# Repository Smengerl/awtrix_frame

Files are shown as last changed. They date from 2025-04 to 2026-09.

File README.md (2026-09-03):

# Ultra-low-cost AWTRIX build




AWTRIX is an amazing and highly flexible visualization companion for smart home applications and more. Originally designed to be flashed onto the Ulanzi Pixel Clock (priced at around $50), it also supports custom builds.

I wanted to create a fully featured custom build with a professional look but at a much lower price point than the original. Since I couldn’t find a comprehensive guide, I decided to create one myself.

Full source code for AWTRIX available here: [AWTRIX repo](https://github.com/Blueforcer/awtrix3) 

Features:
- <B>Affordable</B>: Base build costs under $20, while the full feature set is around $25.
- <B>3D Printer Friendly</B>: Designed to fit most popular 3D printers with a minimum bed size of 175mm.
- <B>High-Quality Display</B>: 32x8 pixel WS2812B LED matrix with a light diffuser for a clean "pixelated" look and a sleek "full black" effect when turned off.
- <B>Customizable Design</B>: Easily interchangeable covers in different colors and textures.
- <B>Flexible Mounting</B>: Can be wall-mounted using nails or screws, or used as a standing or laying device.
- <B>Optional Features</B>:
    - Light sensor for automatic brightness adjustment.
    - DFPlayer Mini for MP3 playback.
    - Buzzer for notifications or alarms.

Notes:
- <B>Battery Support</B>: This build does not include battery support, as the high power demands of the display make it impractical.
- <B>Temperature/Humidity Sensor</B>: A sensor is not included in the housing because the heat generated by the display would affect accuracy. Instead, you can use an external weather station sensor and display its readings on the AWTRIX screen.

Examples:
| Time/date (AWTRIX build in) | Spotify (Custom app) | Customization Example (Different Covers) |
| --- | --- | --- |
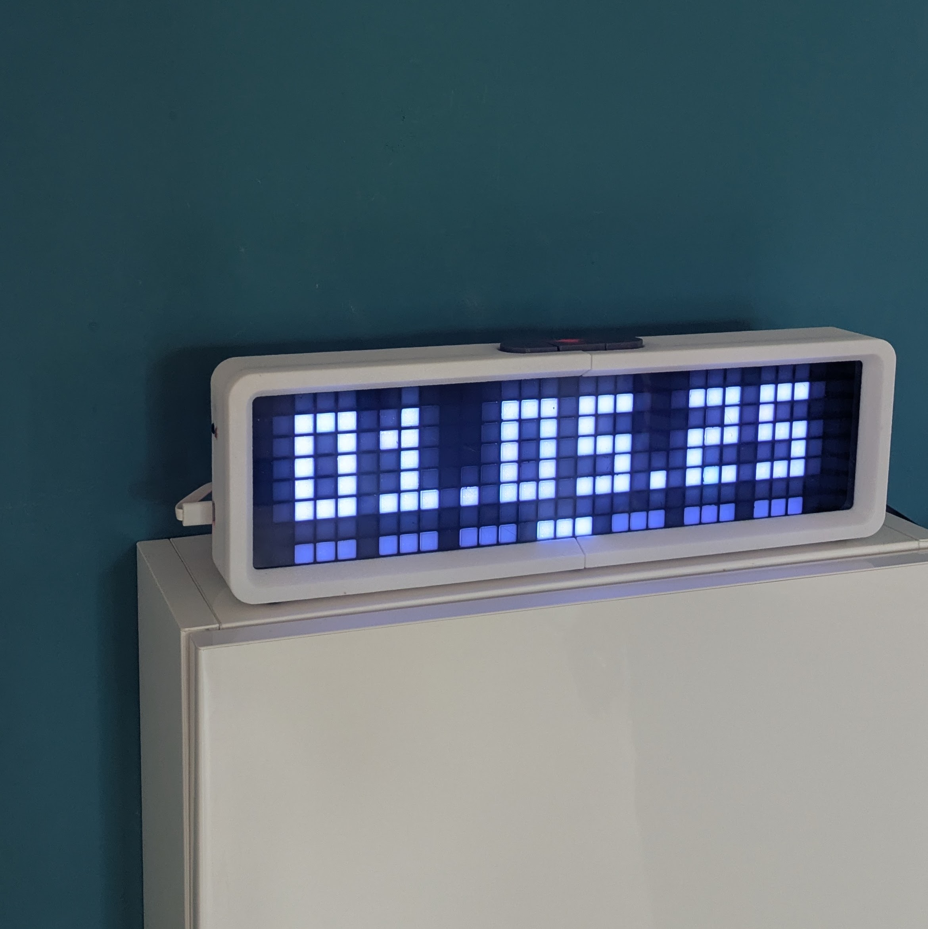
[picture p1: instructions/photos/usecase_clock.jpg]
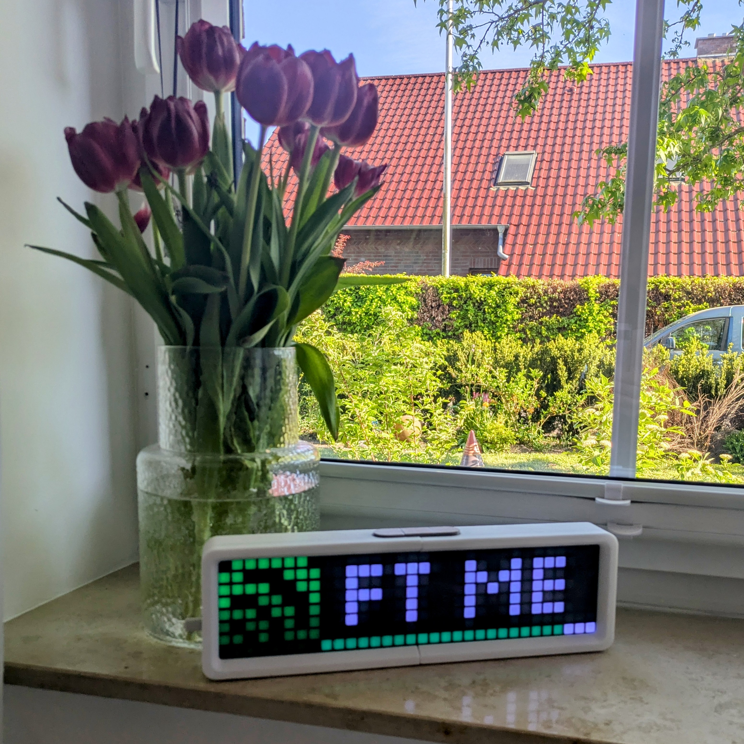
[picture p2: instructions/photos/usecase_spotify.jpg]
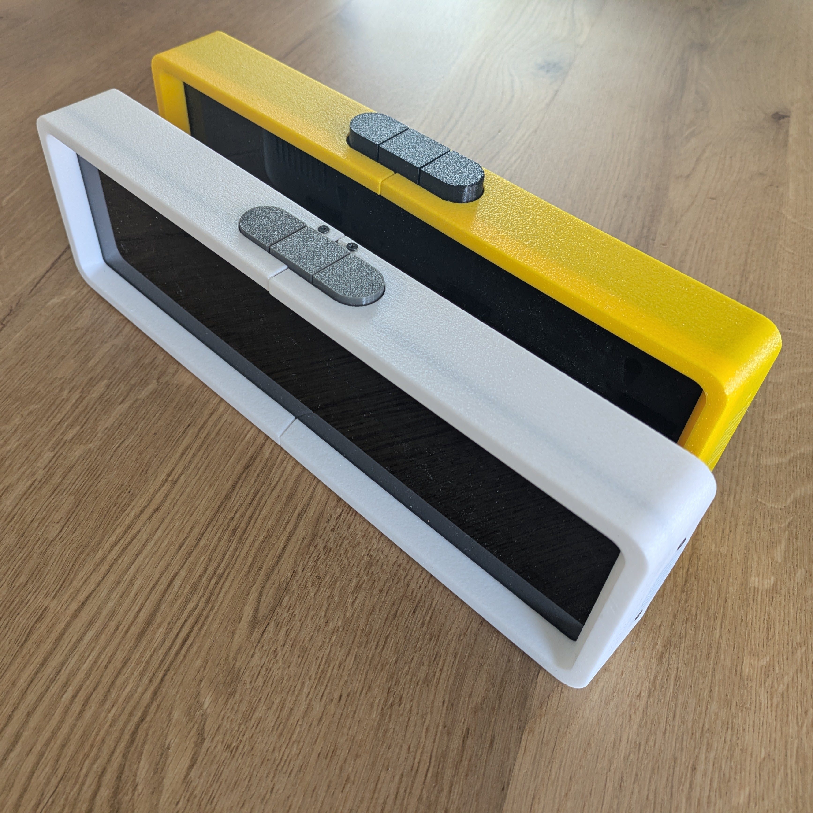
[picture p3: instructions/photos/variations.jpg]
| |  | |

# Index
- [Buy parts](#buy-parts)
- [Printing and assembly](#printing-and-assembly)
- [Customization ideas](#customization-ideas)
- [Acknowledgements](#Acknowledgements)

## Buy parts

Mandatory parts:

| Unit price | Quantity | Partname | Example | Notes |
| --- | --- | --- | --- | ----- |
| 5 USD | 1 | ESP32 Dev Module | <a href="https://de.aliexpress.com/item/1005006124752051.html">AliExpress</a> | Designed for WROVER USB-C type. Other types fit but may require glue |
| 8 USD | 1 | WS2812B matrix 8x32 | <a href="https://de.aliexpress.com/item/4001296811800.html">AliExpress</a> |  |
| 1 USD | 1 | 4 pushbutton element | <a href="https://de.aliexpress.com/item/1005008219549275.html">AliExpress</a> | Connect the outputs of the two middle buttons to "OR" their signal. Unsolder the LED for a cleaner look. |
| 2 USD | 1 | semi-transparent acrylic board | <a href="https://de.aliexpress.com/item/32857098929.html">AliExpress</a> | Optional. Best results with semi-transparent black acrylic (2mm thick). Thinner sheets may need glue. Minimum size: 338x98mm. |
| <1 USD | 25 | Flathead screws M2,5 or M3. 6mm. e.g. DIN 7984 | <a href="https://de.aliexpress.com/item/1005006166060947.html">AliExpress</a> | Use low-head screws (e.g., laptop screws) for a better appearance. |

Optional parts:

| Unit price | Quantity | Partname | Example | Notes |
| --- | --- | --- | --- | ----- |
| 1 USD | 1 | DF Player mini | <a href="https://de.aliexpress.com/item/1005006166800318.html">AliExpress</a> | For MP3 playback |
| 1 USD | 1 | Loudspeaker (8 Ohm) | <a href="https://de.aliexpress.com/item/1005006358049156.html">AliExpress</a> | For MP3 playback. Watch for dimensions |
| <1 USD | 1 | Buzzer | <a href="https://de.aliexpress.com/item/1005004883467830.html">AliExpress</a> | For notifications or alarms. |
| <1 USD | 1 | LDR (GL5516) | <a href="https://de.aliexpress.com/item/1005003021557603.html">AliExpress</a> | For automatic brightness adjustment. |

## Printing and assembly

| 45° | top | -45° | back |
| --- | --- | --- | ---- |
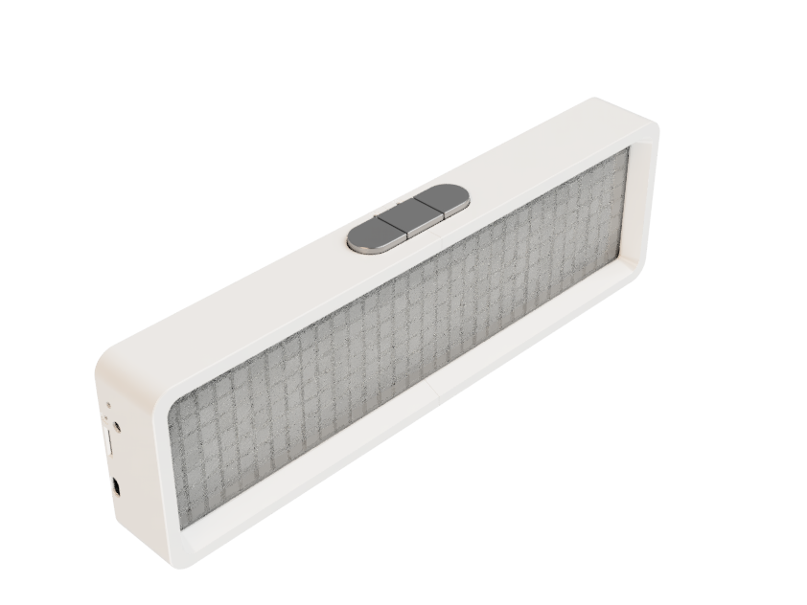
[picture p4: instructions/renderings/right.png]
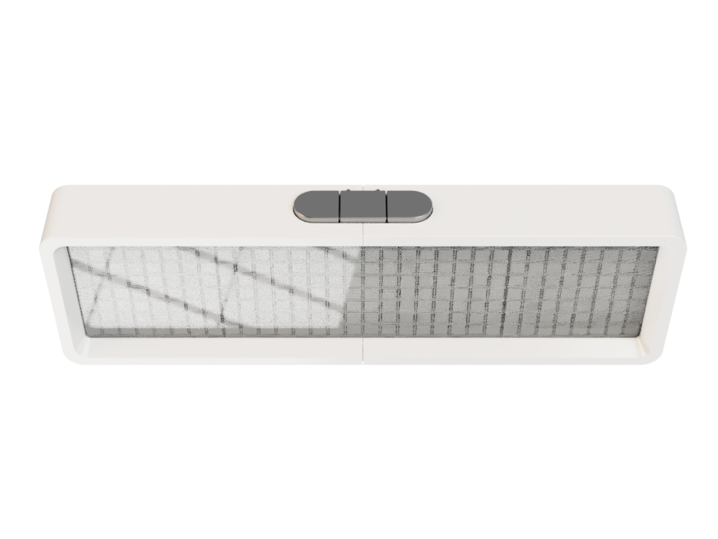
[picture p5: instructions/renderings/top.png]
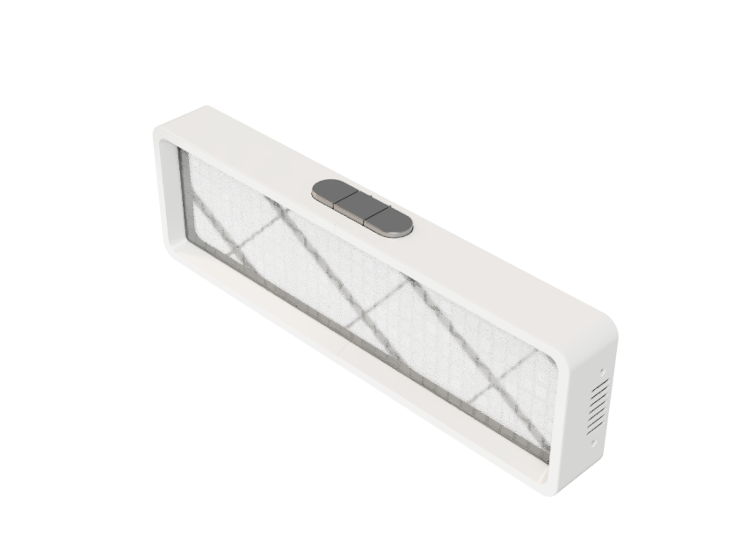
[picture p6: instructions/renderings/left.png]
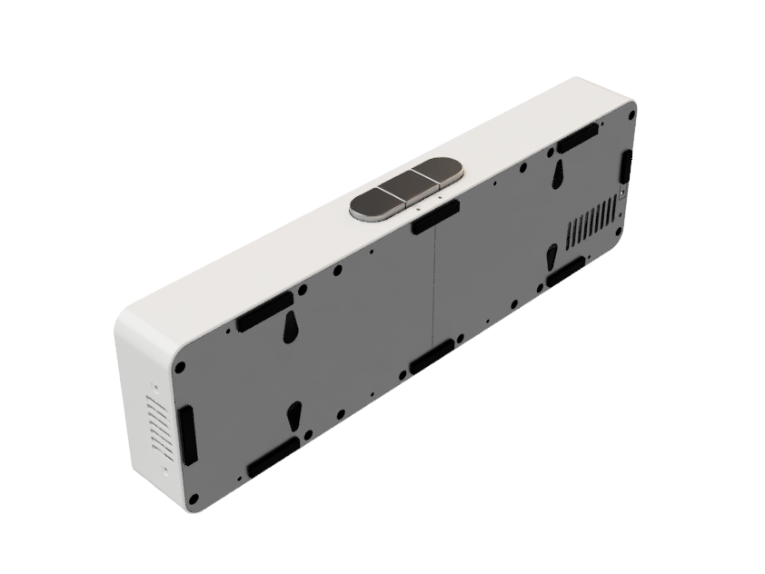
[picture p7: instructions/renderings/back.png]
|  |  |  |  |

The printing and assembly process consist of 5 steps:
- [Step 1: Diffusor](./instructions/step_1.md)
- [Step 2: Base](./instructions/step_2.md)
- [Step 3: Pushbuttons](./instructions/step_3.md)
- [Step 4: Covers](./instructions/step_4.md)
- [Step 5: Anti-slip pads](./instructions/step_5.md)

Printer Settings:
- <B>Material</B>: PETG for most parts, TPU for anti-slip pads, and PLA for the diffuser.
- <B>Orientation</B>: Print parts as shown in the thumbnails for the best results.
- <B>Infill</B>: 20% Gyroid infill with Hilbert curve for first/top layers.
- <B>Supports</B>: Not required unless explicitly mentioned.
- <B>Surface Finish</B>: Use "fuzzy skin" for a textured look on outer walls.
- <B>Rafts/Brims</B>: Not required for any model.

## Customization ideas

The housing offers several customization options:
- Add optional features like the buzzer or light sensor.
- Print covers in different colors or textures.
- Use effects like "fuzzy skin" for a unique appearance.

## Troubleshooting

### External Power

Powering the ESP32 via USB may cause brownouts under LED load. To resolve this, supply regulated 5V directly to the 5V/VIN rail (with a common ground). Use a sufficiently rated 5V supply and thick wiring. Avoid feeding 5V into the USB connector unless using proper power-path/diode.

## Acknowledgements

- Special thanks to Blueforcer for creating the incredible AWTRIX3 project.

## Development

Contributions are welcome.  
See `CONTRIBUTING.md` for details and follow the `CODE_OF_CONDUCT.md` when contributing.

## License

This project is licensed under the Creative Commons Attribution-ShareAlike 4.0 International License (CC BY-SA 4.0) — see `LICENSE.txt` for details or visit http://creativecommons.org/licenses/by-sa/4.0/

## Authors

- Simon Gerlach <https://github.com/Smenger>

---

If something in this README is missing or unclear, please open an issue in the repository so the instructions can be improved.

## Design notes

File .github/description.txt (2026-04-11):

Comprehensive how-to for building an low-cost but professional looking AWTRIX case

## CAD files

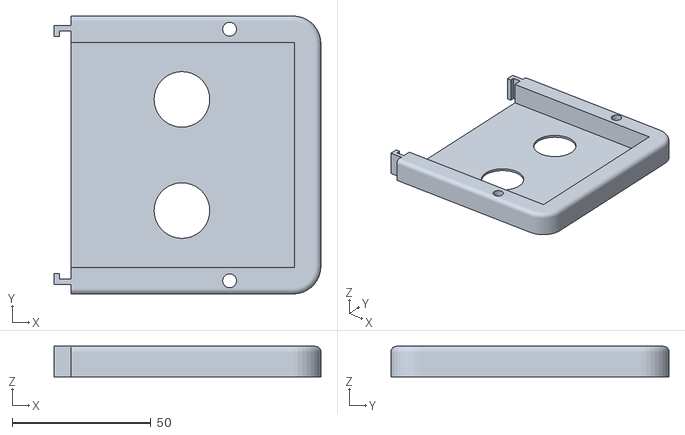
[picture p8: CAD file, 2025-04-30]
print/base/base_right.stl
96.0 x 100.0 x 11.0

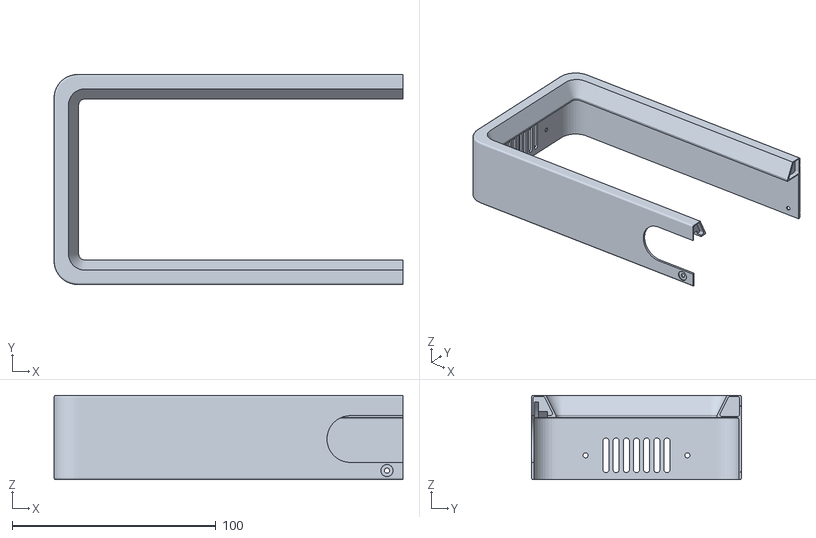
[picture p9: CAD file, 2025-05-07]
print/cover/cover_left.stl
171.5 x 103.2 x 41.5

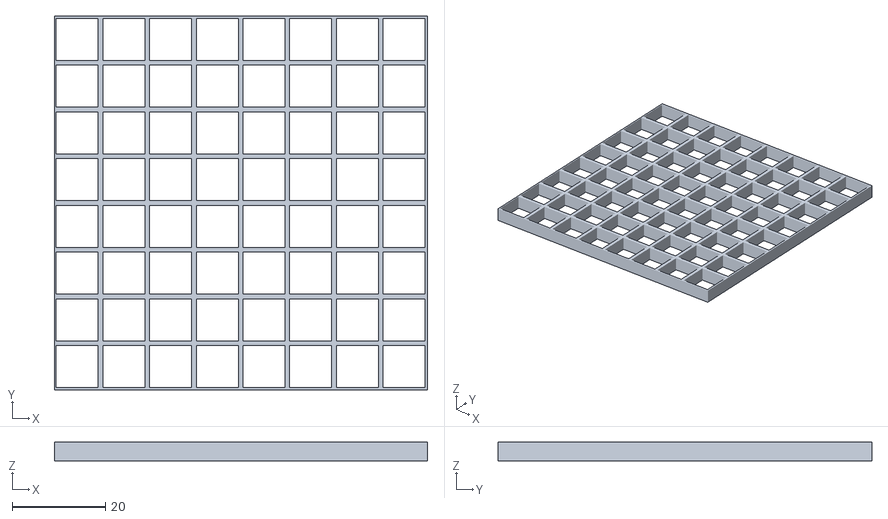
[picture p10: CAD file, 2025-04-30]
print/diffusor/grid_side.stl
79.8 x 80.0 x 4.00

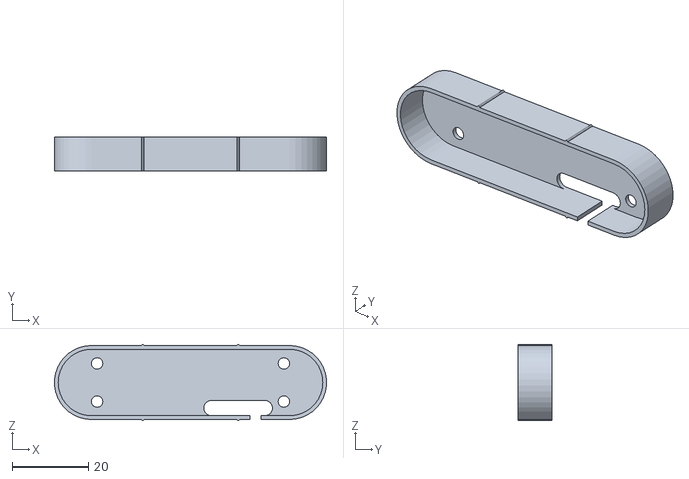
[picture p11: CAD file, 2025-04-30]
print/pushbutton/pushbutton_base.stl
71.3 x 9.00 x 20.0

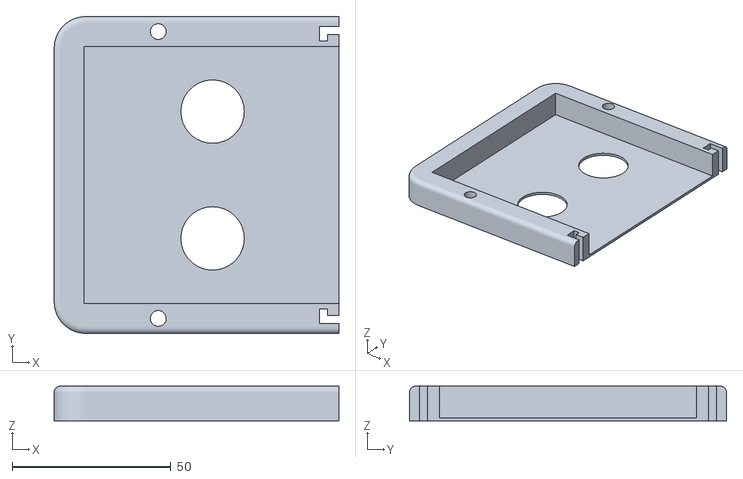
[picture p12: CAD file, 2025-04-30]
print/base/base_left.stl
89.8 x 100.0 x 11.0

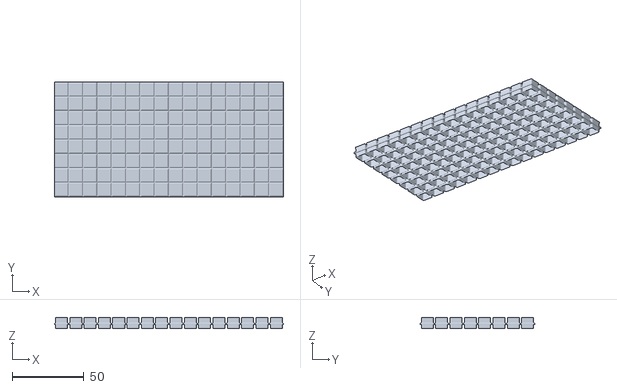
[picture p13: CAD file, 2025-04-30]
print/diffusor/diffusor.stl
159.8 x 80.0 x 8.00

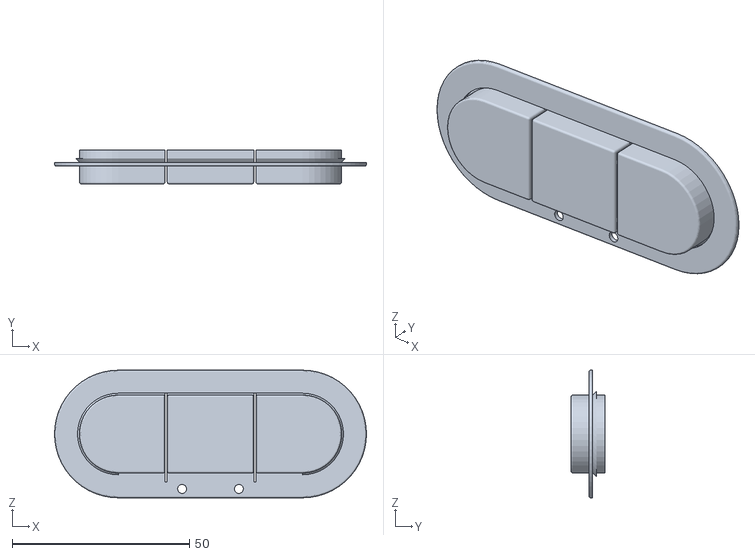
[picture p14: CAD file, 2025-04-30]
print/pushbutton/pushbutton_clicker.stl
88.0 x 9.50 x 36.0

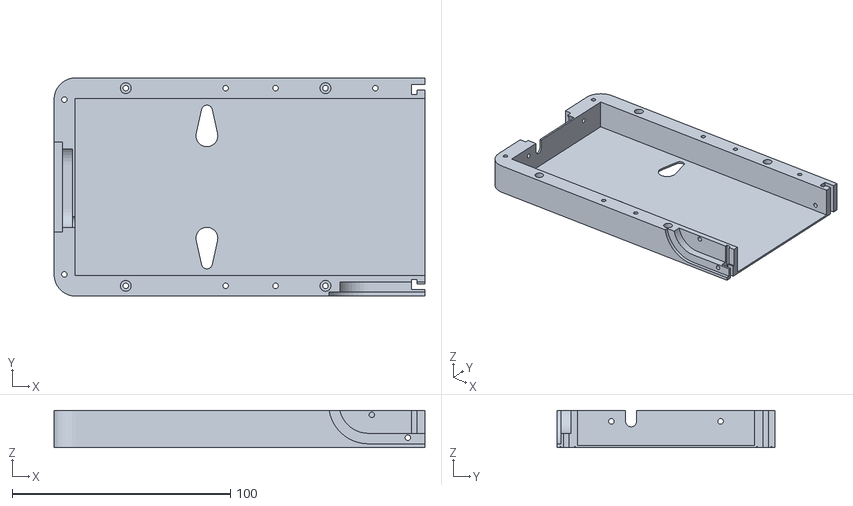
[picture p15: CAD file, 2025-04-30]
print/base/base_lower_left.stl
169.8 x 100.0 x 17.0

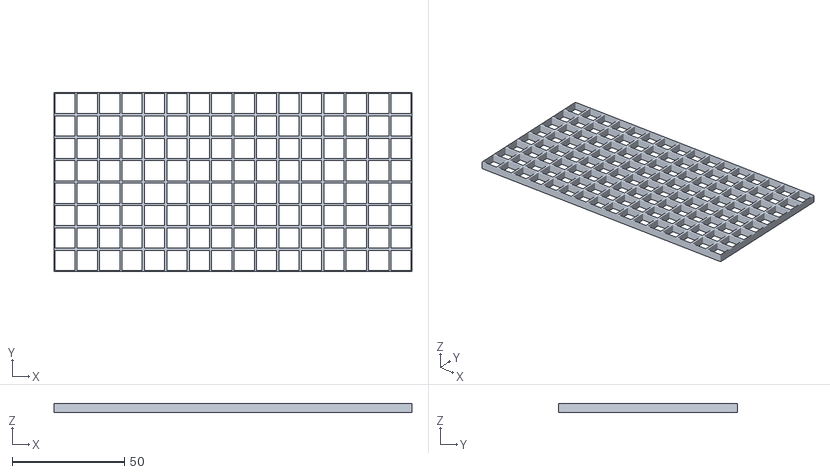
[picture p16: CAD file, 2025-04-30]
print/diffusor/grid_middle.stl
159.7 x 80.0 x 4.00

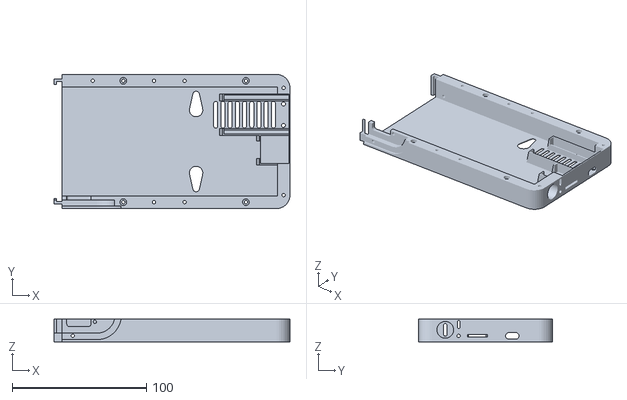
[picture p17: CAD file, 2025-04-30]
print/base/base_lower_right.stl
176.0 x 100.0 x 17.0

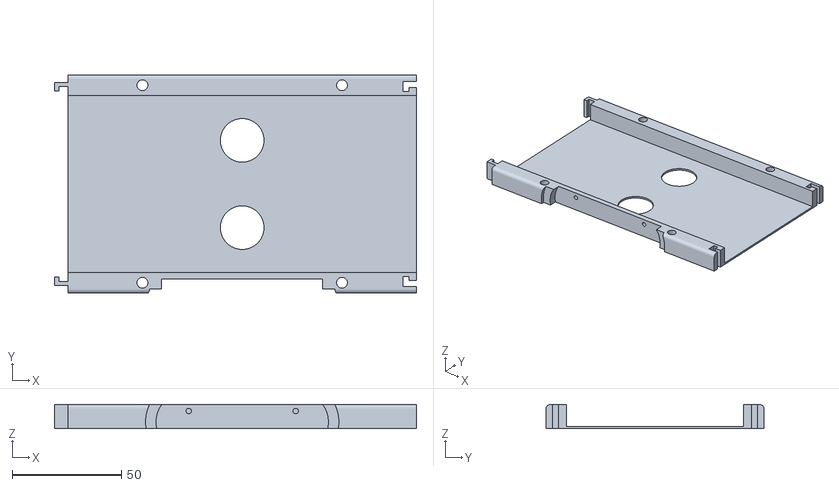
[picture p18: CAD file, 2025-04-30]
print/base/base_middle.stl
165.8 x 100.0 x 11.0

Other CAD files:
print/cover/cover_right.stl

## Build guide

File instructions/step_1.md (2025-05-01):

# Step 1: Diffusor

3D-Printed Parts:

| Filename | Thumbnail | Required | Notes |
| --- | --- | --- | ---|
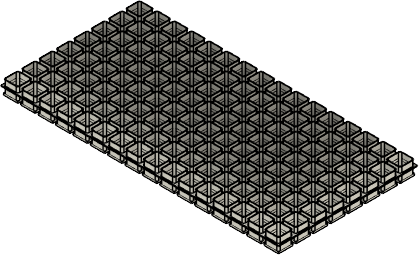
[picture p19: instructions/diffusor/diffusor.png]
| `../print/diffusor/diffusor.stl` |  | 2 | Standard white PLA gave best diffusor effect |
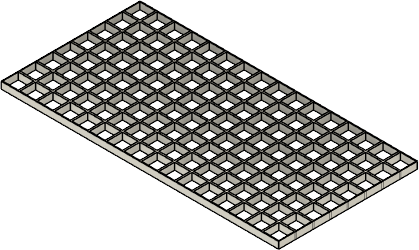
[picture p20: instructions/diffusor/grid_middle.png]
| `../print/diffusor/grid_middle.stl` |  | 2 | Use full black PETG for best stability and contrast |
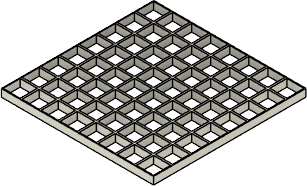
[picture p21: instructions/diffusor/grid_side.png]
| `../print/diffusor/grid_side.stl` |  | 4 | Use full black PETG for best stability and contrast |

Assembly:
- Snap in the grids to the diffusor from both directions
- Use the larger "middle grid" to tie both diffusor part together as shown in assembly animation
- One outside wall of the "diffusor_side" is a little thinner than the other wall. Use this to face to the middle grid to achieve best look  
- make sure the upper grid is fully pressed in so that surface of diffusor and grid is fully leveled, this may require some force

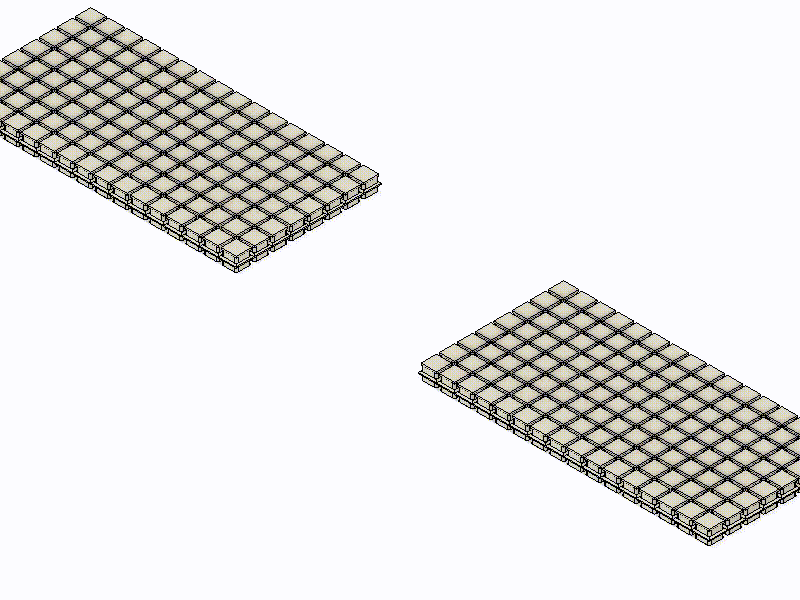
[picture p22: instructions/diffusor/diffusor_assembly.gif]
assembly


Detailed view of the different layers of the diffusor in its final assembly position:
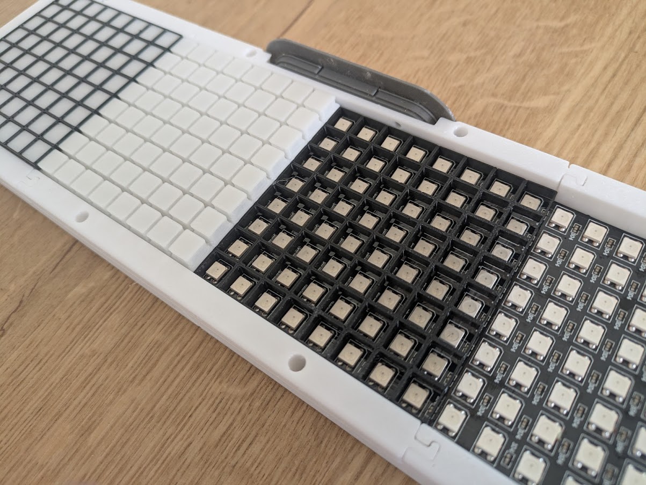
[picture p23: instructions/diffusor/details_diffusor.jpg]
detail


[Next step](./step_2.md) | 
[Back to overview](../README.md)

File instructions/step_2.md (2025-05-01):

# Step 2: Base

Note: no part of the base will be visible any longer once the cover is attached, so you can use up leftover filament

| Filename | Thumbnail | Required | Notes |
| --- | ---| --- | ---|
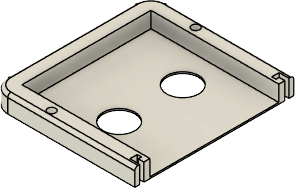
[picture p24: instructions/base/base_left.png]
| `../print/base/base_left.stl` |  | 1 | Invisible in assembled state |
| `../print/base/base_right.stl` |  | 1 | Invisible in assembled state |
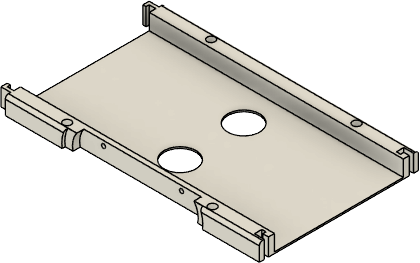
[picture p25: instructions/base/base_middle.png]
| `../print/base/base_middle.stl` |  | 1 | Invisible in assembled state |
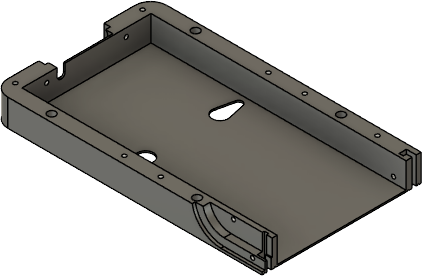
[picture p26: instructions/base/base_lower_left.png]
| `../print/base/base_lower_left.stl`  |   | 1 | Invisible in assembled state |
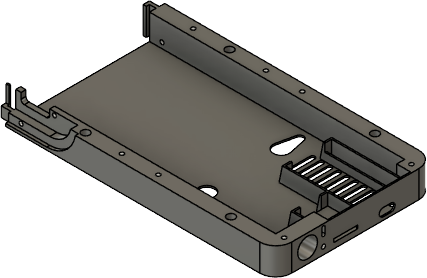
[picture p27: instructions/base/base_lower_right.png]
| `../print/base/base_lower_right.stl` |  | 1 | Invisible in assembled state |

Assembly:
- Connect the parts of the lower base via the locks 
- Most electronics go into the lower part of the base (ESP, DF player, buzzer, loudspeaker, LDR). Make sure to have them installed before going on
- Connect the parts of the upper base via the locks
- The WS2812 LED grid is laid in the sunken part of the upper base. Solder the connection wires to the matrix and connect them to the electronics in the lower base
- Prepare push button assembly by soldering the wires of the 4 button module to the ESP and make them stick out the holes  
- Put upper part of base atop of lower part
- Screw both parts toger via screws from bottom (the screw holes on the upper part are foreseen for wall hangings via screws)

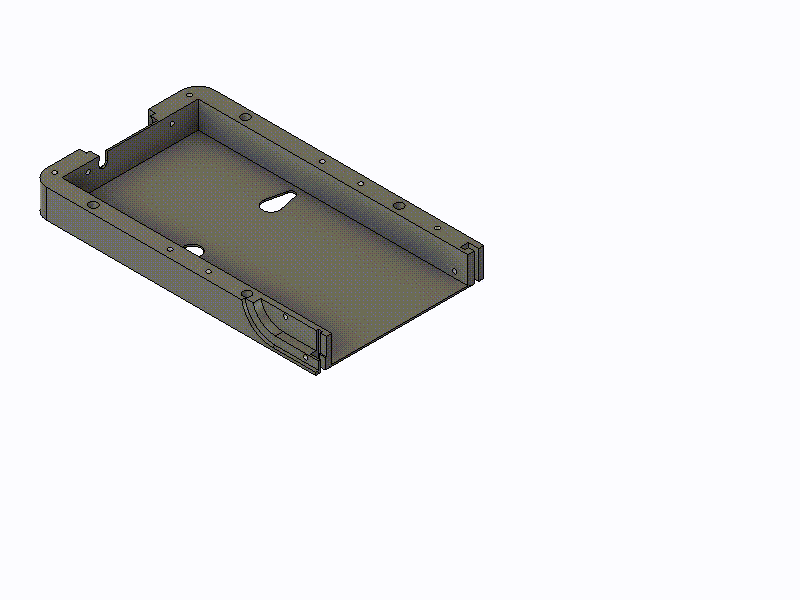
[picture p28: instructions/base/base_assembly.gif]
assembly


[Previous step](./step_1.md) |
[Next step](./step_3.md) |
[Back to overview](../README.md)

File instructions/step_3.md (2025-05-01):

# Step 3: Pushbuttons

| Filename | Thumbnail | Required | Notes |
| --- | --- | --- | ---|
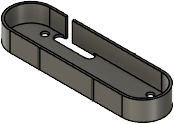
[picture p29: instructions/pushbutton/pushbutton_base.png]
| `../print/pushbutton/pushbutton_base.stl` |  | 1 | Invisible in assembled state |
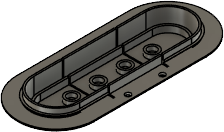
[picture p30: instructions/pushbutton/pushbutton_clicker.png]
| `../print/pushbutton/pushbutton_clicker.stl` |  | 1 | Make sure to print in the depicted direction and enable light supports |

Assembly:
- Place 4 button module PCN on top of pushbutton base and screws it to the base
- Press pushbutton top "clicker" to the 4 button module. Each button's hat need to fit into one of the foreseen holes in the clicker 

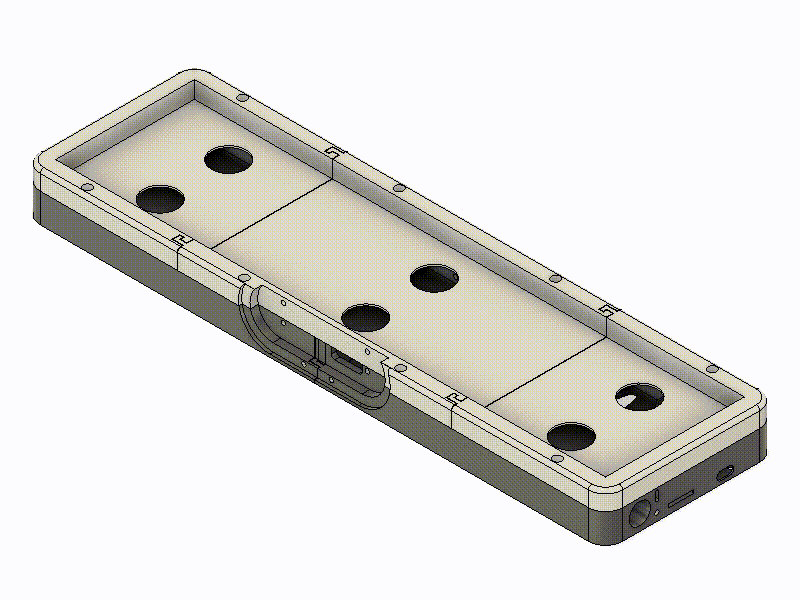
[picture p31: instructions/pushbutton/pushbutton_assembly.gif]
assembly


[Previous step](./step_2.md) |
[Next step](./step_4.md) |
[Back to overview](../README.md)

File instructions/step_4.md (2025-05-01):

# Step 4: Covers

Notes:
- Consider fuzzy skin for outside walls
- Use a nice color to personalize your AWTRIX
- Priting in depicted direction requires supports only at the location of the pushbuttons (consider disable auto supports and use paint-on supports at these locations)

| Filename | Thumbnail | Required | Notes |
| --- | --- | --- | ---|
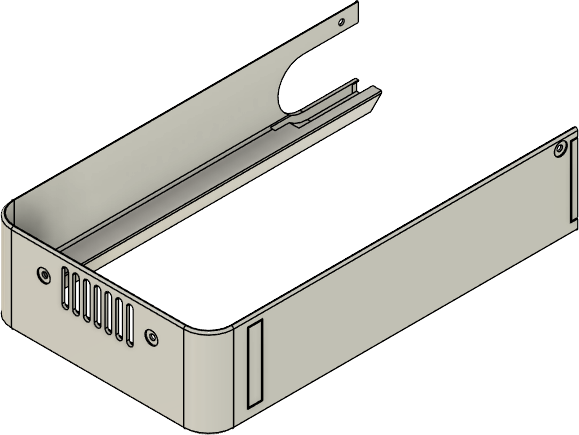
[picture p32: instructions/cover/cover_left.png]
| `../print/cover/cover_left.stl`  |   | 1 | |
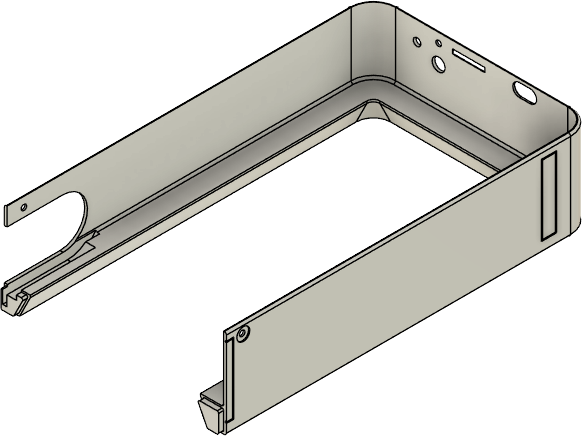
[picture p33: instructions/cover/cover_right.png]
| `../print/cover/cover_right.stl` |  | 1 | |

Cut the acrylic board as shown:
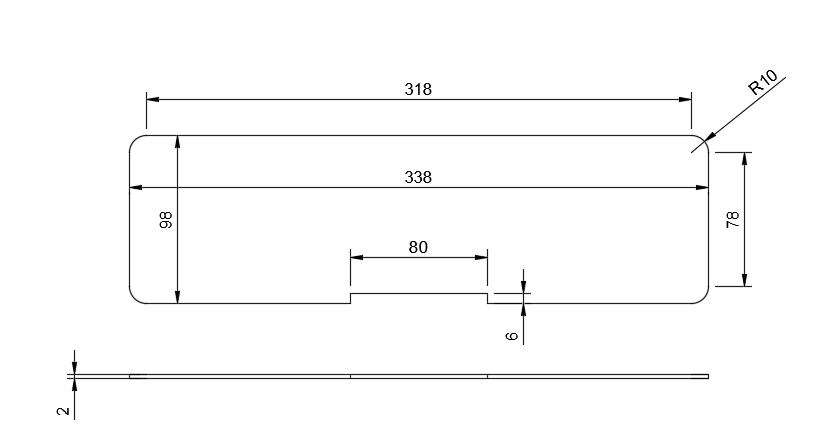
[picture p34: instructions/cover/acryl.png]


Assembly:
- Place the diffusor on top of the LED matrix in the sunken part of the upper base. Adjust the peaces in a way that the surface of the diffusor aligns with the one of the upper base
- place the acrylic board on top of the base and diffusor
- Slide both parts of the cover on the base with the diffusor and acrylic board
- Screw the cover to the base 

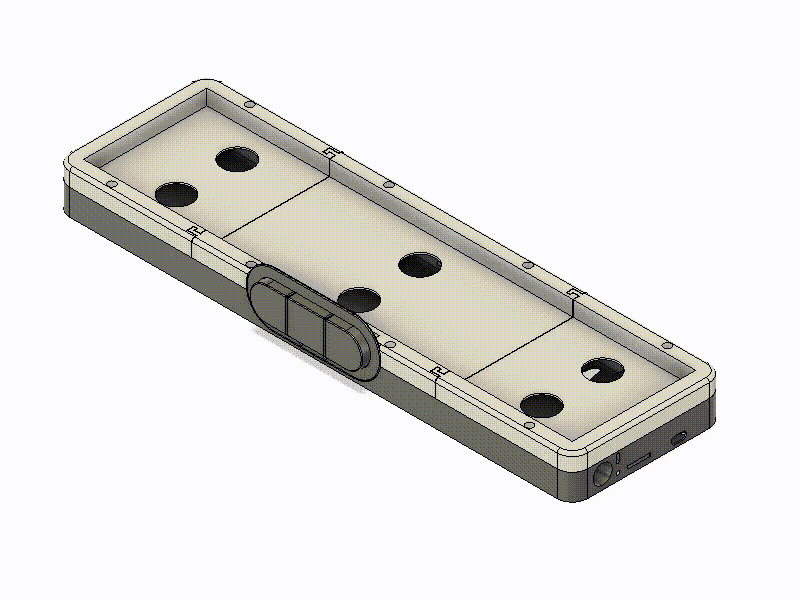
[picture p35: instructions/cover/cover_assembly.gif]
assembly


[Previous step](./step_3.md) |
[Next step](./step_5.md) |
[Back to overview](../README.md)

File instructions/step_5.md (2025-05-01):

# Step 5: Anti-slip pads
Optionally you might want to add TPU [anti-slip pads](../print/antislip/antislip.stl) to the AWTRIX which gives it a solid stand in laying (8 pads) and/or upright position (3 pads).
Assemble these pads at the indicated locations on the base and cover via double sided tape. 

Alternatively you can use standard non-slip pads or even cut peaces of standard rubber pads and attach them with double sided tape.

Location of the pads for upright position:
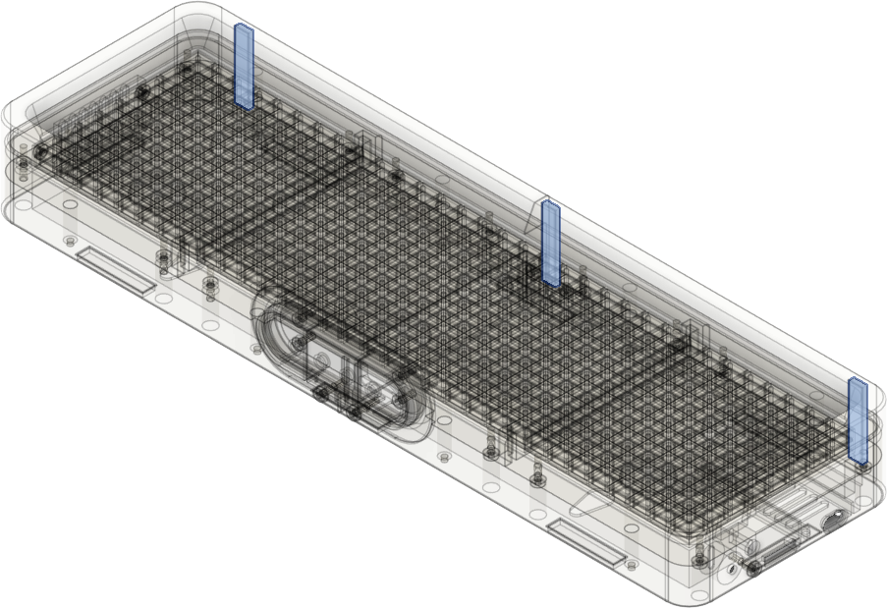
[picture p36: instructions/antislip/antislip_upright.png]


Location of the pads for laying or wall hanging position:
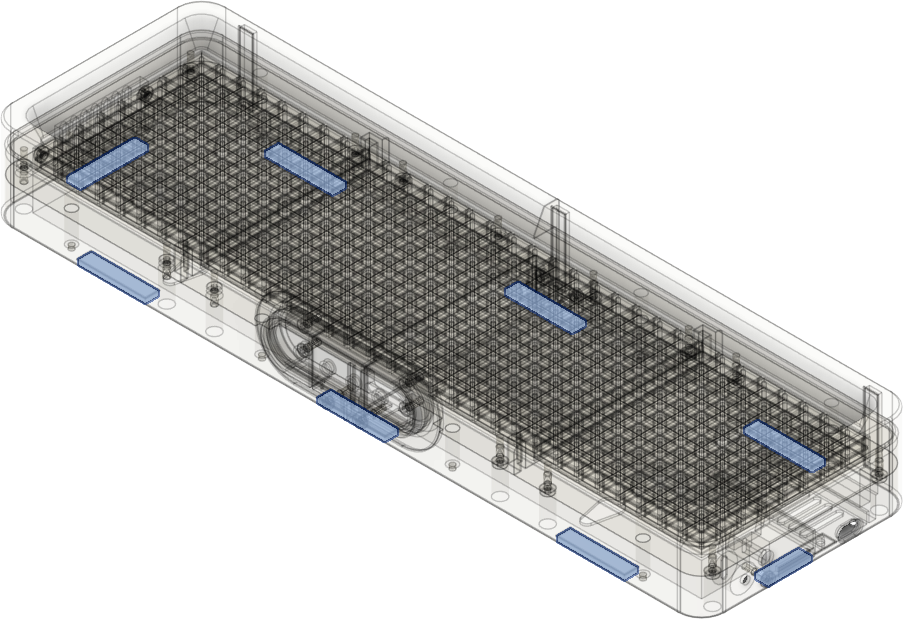
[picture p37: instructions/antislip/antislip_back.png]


[Previous step](./step_4.md) |
[Back to overview](../README.md)

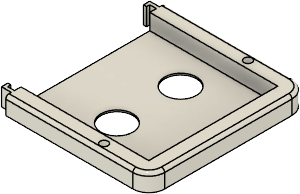
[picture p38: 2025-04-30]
instructions/base/base_right.png

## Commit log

2025-05-01 Added assembly instruction for base
2025-05-01 Added assembly video for pushbuttons and new acryl plate cutting plan
2025-05-01 Added assembly video for cover
2025-05-03 Added overlapping cover elements to achieve more cleaner look
    [cover_left.stl, cover_right.stl]
2025-05-07 Improved overlaps for better printability with coarser printers
    [cover_left.stl, cover_right.stl]
2026-04-10 Add troubleshooting section to README
    Added troubleshooting section for external power issues with ESP32.
2026-09-03 Fixed broken link to ali express push button PCB
